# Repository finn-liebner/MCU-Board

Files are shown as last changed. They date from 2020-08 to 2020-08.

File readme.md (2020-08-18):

## MCU-Board

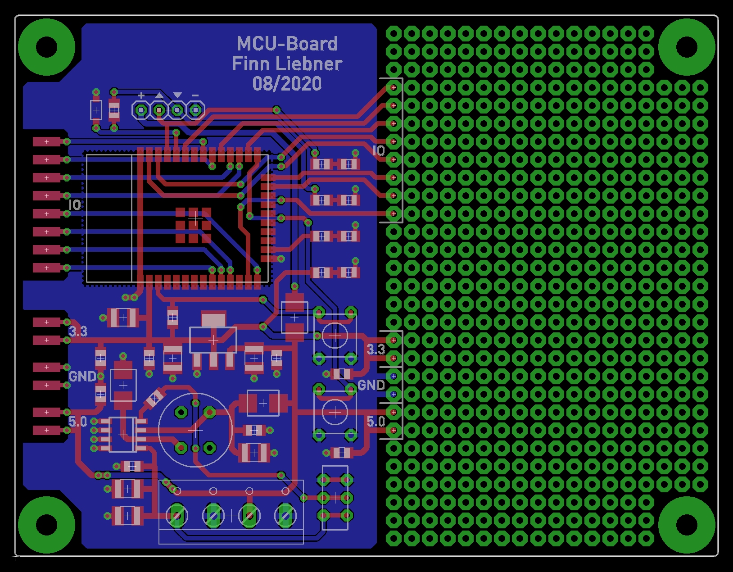
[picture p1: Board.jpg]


### Bauteile

| Stückzahl | Mouser |
|---|---|
| 1x | [ESP WROOM 32D](https://www.mouser.de/ProductDetail/356-ESPWROOM3200PS3) |
| 2x | [Taster](https://www.mouser.de/ProductDetail/506-FSM4JH) |
| 1x | [Schalter](https://www.mouser.de/ProductDetail/611-JS202011CQN) |
| 1x | [LDO 3.3V](https://www.mouser.de/ProductDetail/621-AZ1117IH-3.3TRG1) |
| 1x | [Step-Down 5.0V](https://www.mouser.de/ProductDetail/621-AP1509-50SG-13) |
| 1x | [Spule 47µH](https://www.mouser.de/ProductDetail/815-AIUR-08-470K) |
| 3x | [Schottkydiode](https://www.mouser.de/ProductDetail/750-SS34B-HF) |
| 1x | [Zenerdiode 3.3V](https://www.mouser.de/ProductDetail/621-MMSZ5226B-F) |
| 3x | [LED Rot](https://www.mouser.de/ProductDetail/720-LHR974-LP-1) |
| 1x | [LED Grün](https://www.mouser.de/ProductDetail/720-LGR971-KN-1) |
| 8x | [Kondensator 100nF](https://www.mouser.de/ProductDetail/963-UMK212BJ104MG-T) |
| 6x | [Kondensator 10µF](https://www.mouser.de/ProductDetail/963-UMK325C7106KM-T)  |
| 4x | [Widerstand 82Ω](https://www.mouser.de/ProductDetail/71-CRCW0805-82-E3) |
| 2x | [Widerstand 4.7kΩ](https://www.mouser.de/ProductDetail/71-CRCW0805-4.7K-E3)  |
| 1x | [Widerstand 36kΩ](https://www.mouser.de/ProductDetail/71-CRCW080536K0FKEA) |
| 1x | [Anschlussblock](https://www.mouser.de/ProductDetail/649-220316-H041B01LF) |
| 1x | Steckleiste / 2.54 / 4-Pin |

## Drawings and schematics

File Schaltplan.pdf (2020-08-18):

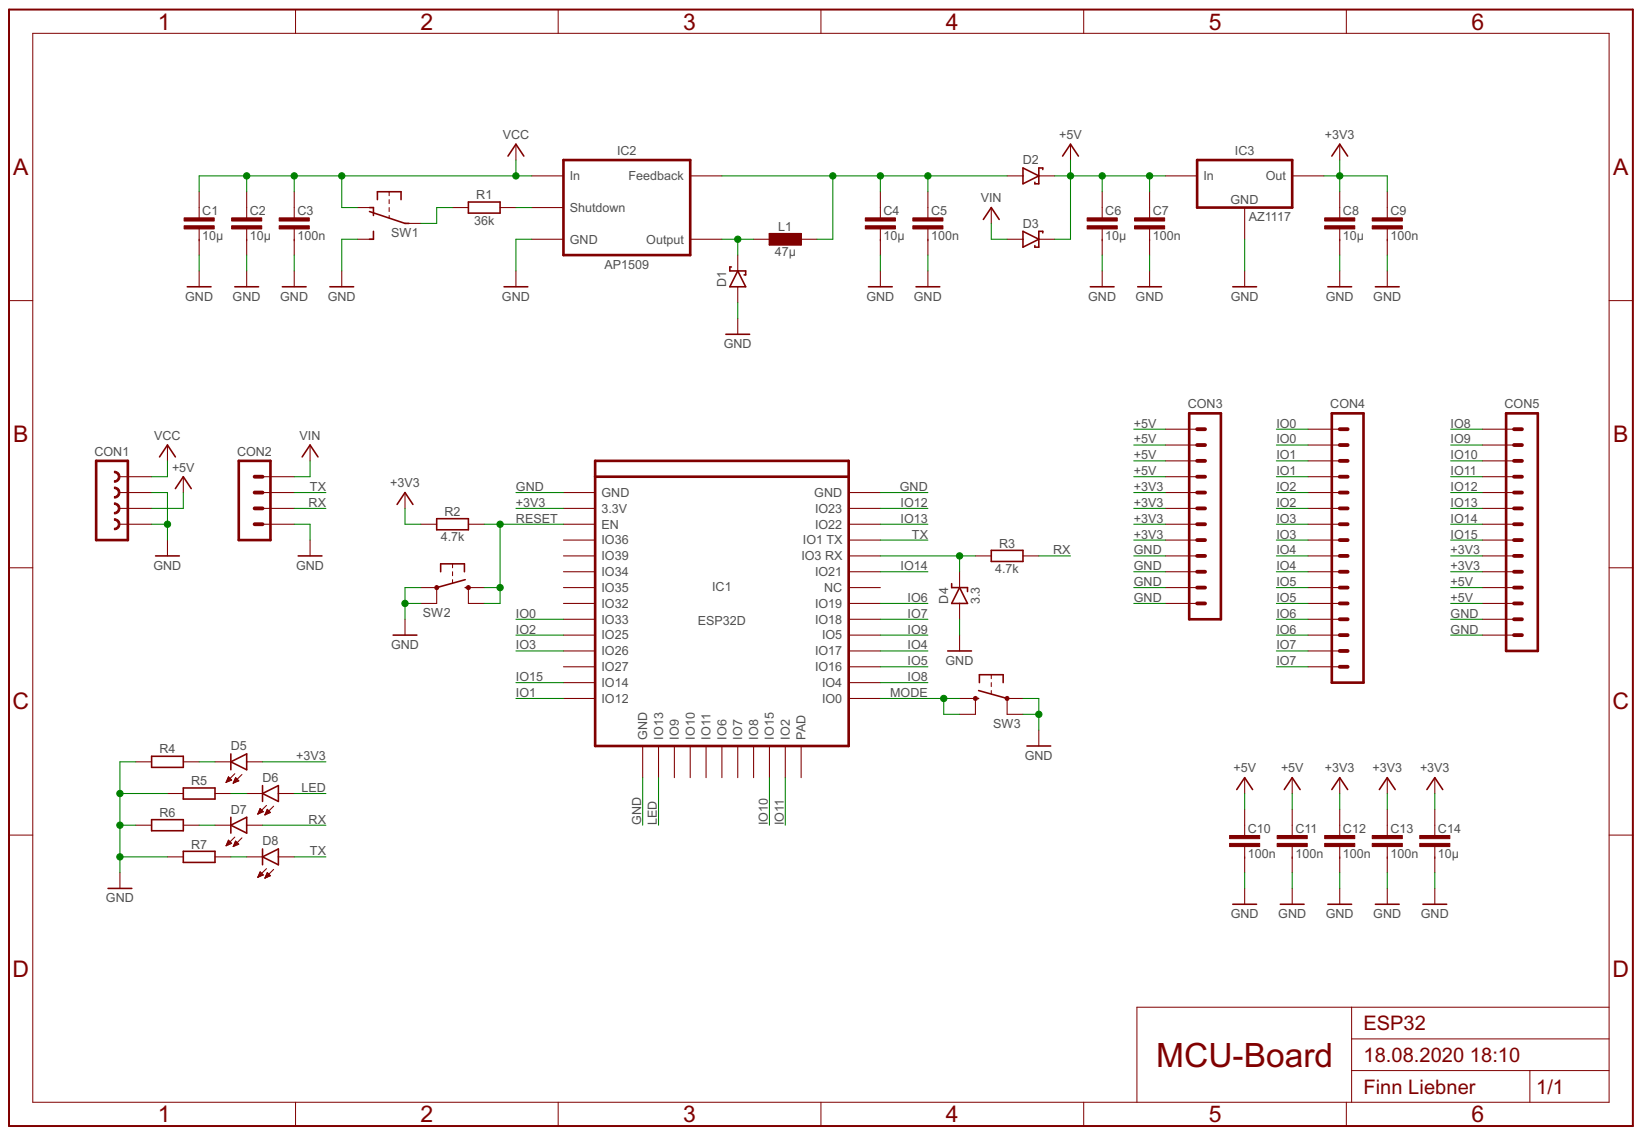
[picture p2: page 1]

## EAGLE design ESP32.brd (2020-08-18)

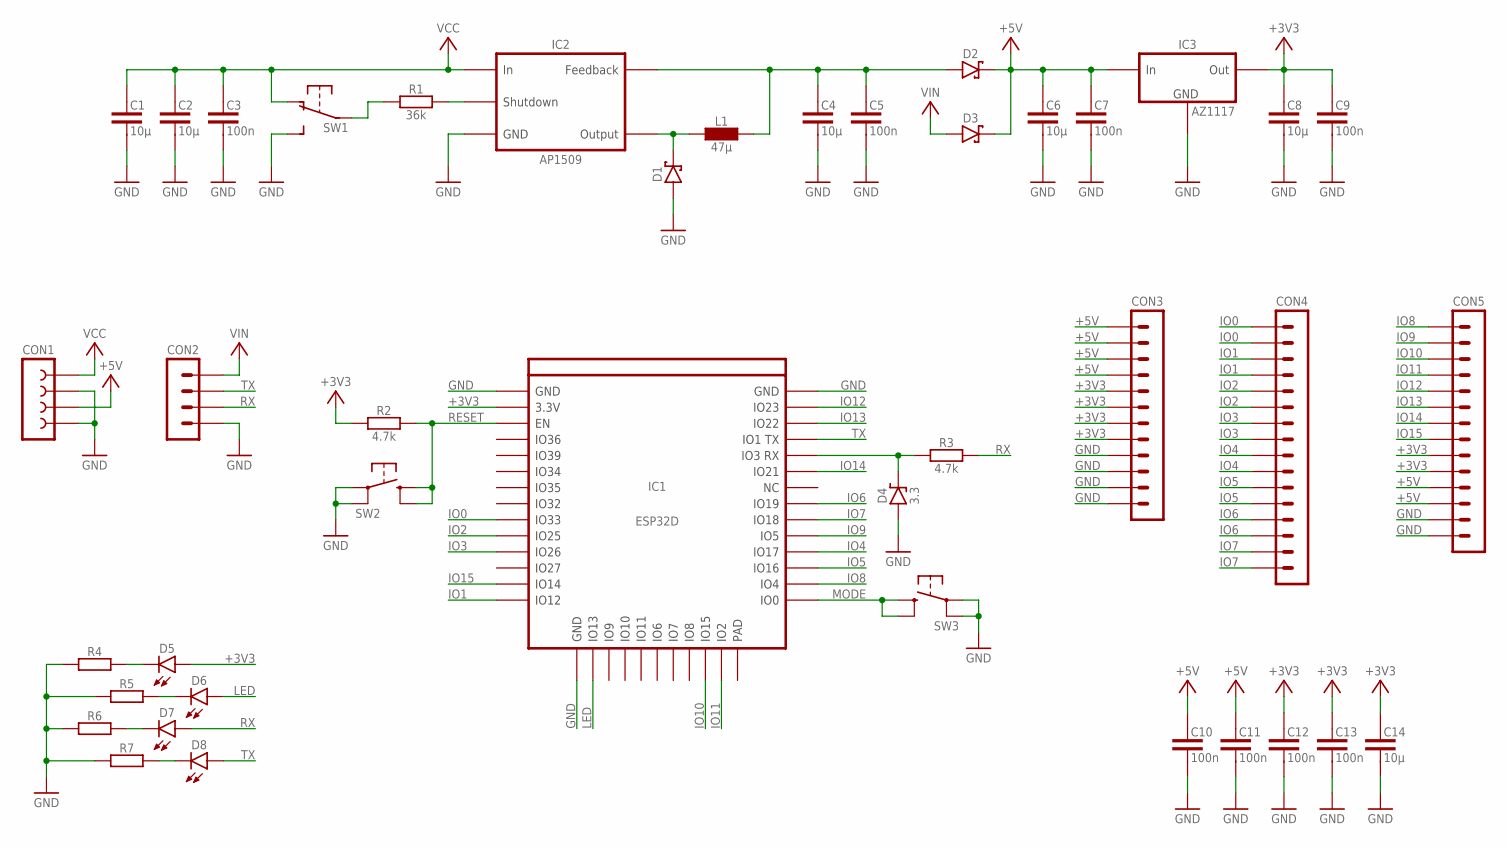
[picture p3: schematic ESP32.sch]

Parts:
C1, C2, C4, C6, C8, C14: 10µ; C1210
C3, C5, C7, C9, C10, C11, C12, C13: 100n; C0805
CON1: CON-4
CON2: PIN-4
D1, D2, D3: D-SCHOTTKY; DO214AA-2
D4: 3.3; SOD123-2
D5, D6, D7, D8: LED; D0805
IC1: ESP32D; ESP32
IC2: AP1509; SO8
IC3: AZ1117; SOT223
L1: 47µ; L6
P1, P2, P15, P16: 5V; PAD
P3, P4, P17, P18: 3V; PAD
P5, P6, P19, P20: 0V; PAD
P7, P21: IO0; PAD
P8, P22: IO1; PAD
P9, P23: IO2; PAD
P10, P24: IO3; PAD
P11, P25: IO4; PAD
P12, P26: IO5; PAD
P13, P27: IO6; PAD
P14, P28: IO7; PAD
P30: IO8; PAD2
P31: IO9; PAD2
P32: IO10; PAD2
P33: IO11; PAD2
P34: IO12; PAD2
P35: IO13; PAD2
P39, P45: 5V; PAD2
P40, P44: 3V; PAD2
P41, P46: 0V; PAD2
P42: IO14; PAD2
P43: IO15; PAD2
R1: 36k; R0805
R2, R3: 4.7k; R0805
R4, R5, R6, R7: R; R0805
SW1: SW1
SW2, SW3: SW2

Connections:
+3V3: C8.1, C9.1, C12.1, C13.1, C14.1, D5.A, IC1.2 (3.3V), IC3.2 (OUT), IC3.4 (OUT), P3.1, P4.1, P17.1, P18.1, P40.P$1, P44.P$1, R2.1
+5V: C6.1, C7.1, C10.1, C11.1, CON1.3, D2.K (C), D3.K (C), IC3.3 (VCC), P1.1, P2.1, P15.1, P16.1, P39.P$1, P45.P$1
GND: C1.2, C2.2, C3.2, C4.2, C5.2, C6.2, C7.2, C8.2, C9.2, C10.2, C11.2, C12.2, C13.2, C14.2, CON1.2, CON1.4, CON2.4, D1.A, D4.A, IC1.1 (GND0), IC1.15 (GND1), IC1.38 (GND2), IC2.5 (GND), IC2.6 (GND), IC2.7 (GND), IC2.8 (GND), IC3.1 (GND), P5.1, P6.1, P19.1, P20.1, P41.P$1, P46.P$1, R4.2, R5.2, R6.2, R7.2, SW1.3 (2), SW1.6 (2), SW2.1 (P0), SW2.3 (P1), SW3.1 (P0), SW3.3 (P1)
IO0: IC1.9 (IO33), P7.1, P21.1
IO1: IC1.14 (IO12), P8.1, P22.1
IO2: IC1.10 (IO25), P9.1, P23.1
IO3: IC1.11 (IO26), P10.1, P24.1
IO4: IC1.28 (IO17), P11.1, P25.1
IO5: IC1.27 (IO16), P12.1, P26.1
IO6: IC1.31 (IO19), P13.1, P27.1
IO7: IC1.30 (IO18), P14.1, P28.1
IO8: IC1.26 (IO4), P30.P$1
IO9: IC1.29 (IO5), P31.P$1
IO10: IC1.23 (IO15), P32.P$1
IO11: IC1.24 (IO2), P33.P$1
IO12: IC1.37 (IO23), P34.P$1
IO13: IC1.36 (IO22), P35.P$1
IO14: IC1.33 (IO21), P42.P$1
IO15: IC1.13 (IO14), P43.P$1
LED: D6.A, IC1.16 (IO13)
MODE: IC1.25 (IO0), SW3.2 (S0), SW3.4 (S1)
unnamed: IC2.4 (SHDN), R1.2
unnamed: D1.K (C), IC2.2 (OUT), L1.1
unnamed: R1.1, SW1.2 (C), SW1.5 (C)
unnamed: C4.1, C5.1, D2.A, IC2.3 (FB), L1.2
unnamed: D5.K, R4.1
unnamed: D4.K (C), IC1.34 (IO3), R3.1
unnamed: D6.K, R5.1
unnamed: D7.K, R6.1
unnamed: D8.K, R7.1
RESET: IC1.3 (EN), R2.2, SW2.2 (S0), SW2.4 (S1)
RX: CON2.3, D7.A, R3.2
TX: CON2.2, D8.A, IC1.35 (IO1)
VCC: C1.1, C2.1, C3.1, CON1.1, IC2.1 (IN), SW1.1, SW1.4 (1)
VIN: CON2.1, D3.A

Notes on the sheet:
CON3
CON4
CON5

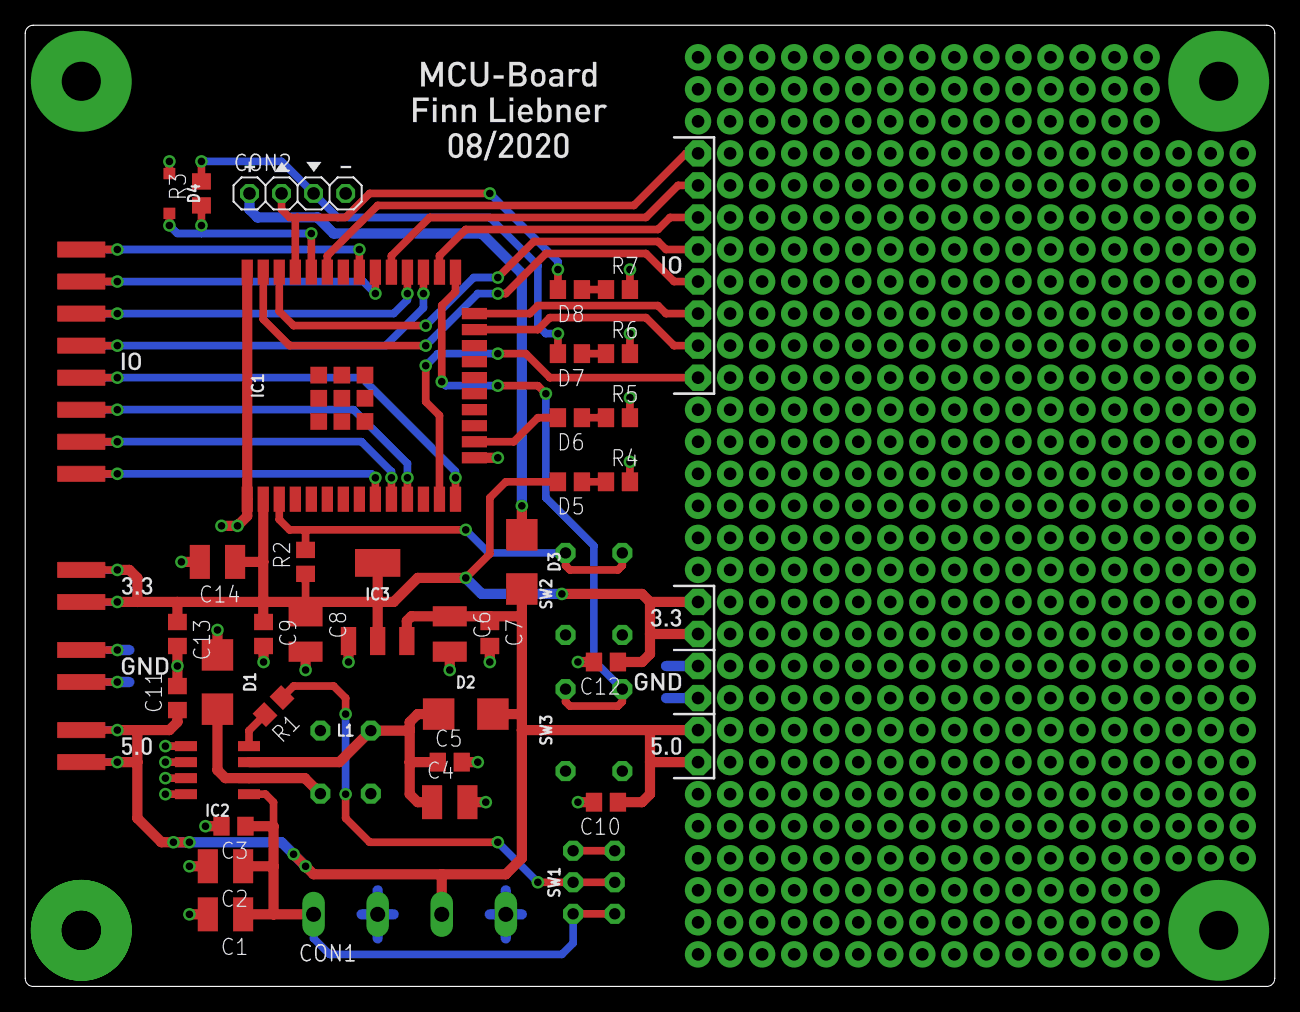
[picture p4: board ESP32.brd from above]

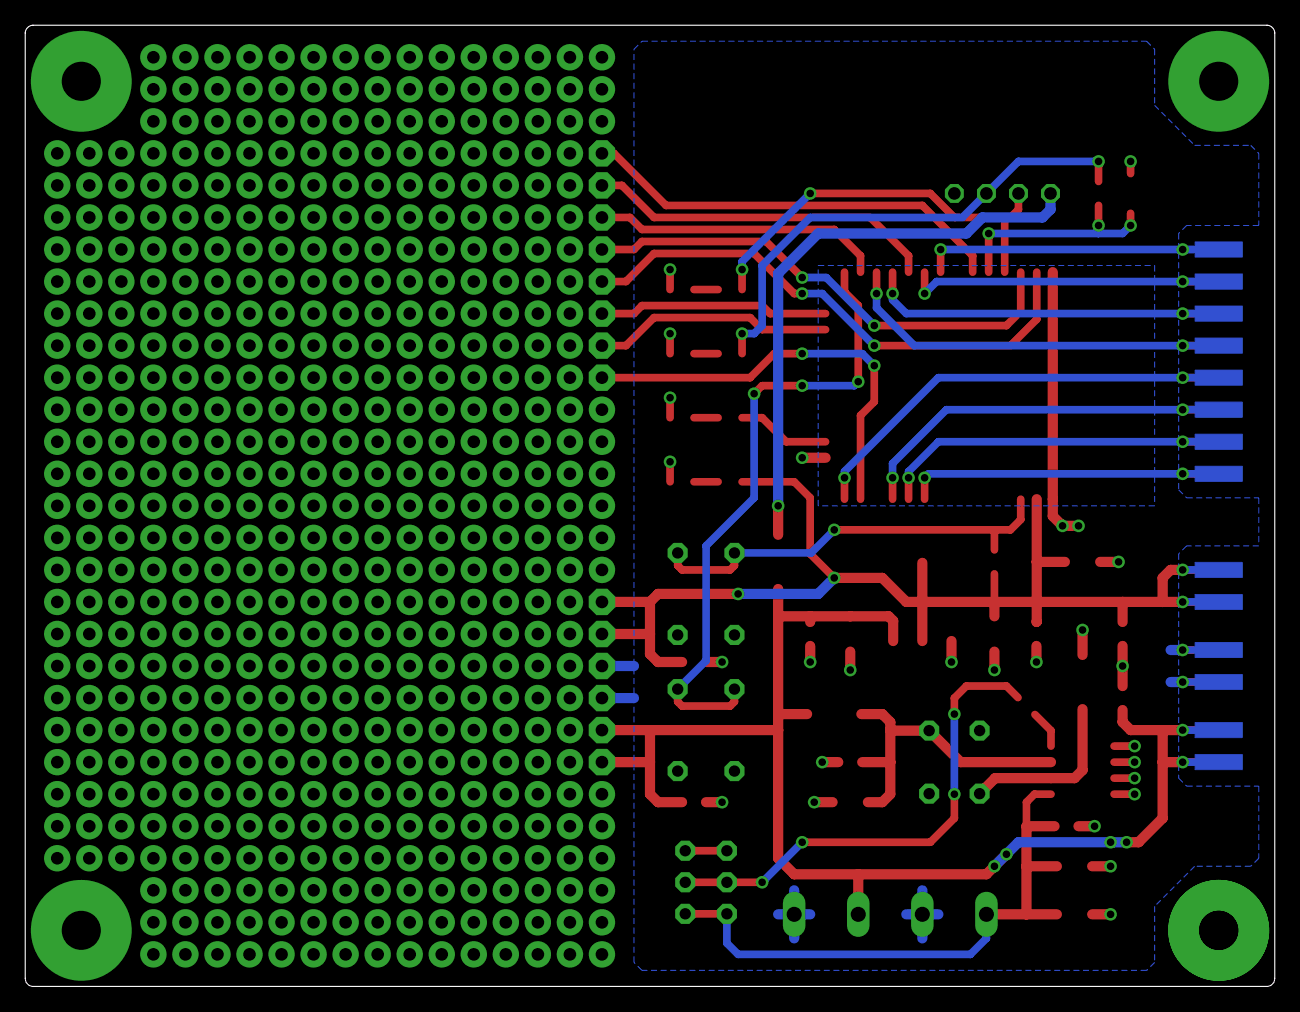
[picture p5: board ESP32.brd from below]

Board: 2 copper layers, 99.1 x 76.2 mm, 80 parts (14 on the bottom side), 35 nets.
